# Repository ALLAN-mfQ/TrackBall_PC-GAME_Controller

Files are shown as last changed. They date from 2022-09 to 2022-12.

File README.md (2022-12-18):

## update

2022/12/18  
ジャイロセンサーを追加しました。  

メインボードを新しくしてMPU6050を搭載しました。  
新しい基板はボタンを2つ追加できるようにしてあります。　必要に応じて改造可能です。  
[+GYRO](https://github.com/ALLAN-mfQ/TrackBall_PC-GAME_Controller/tree/main/%2BGYRO)にデータを公開しています。

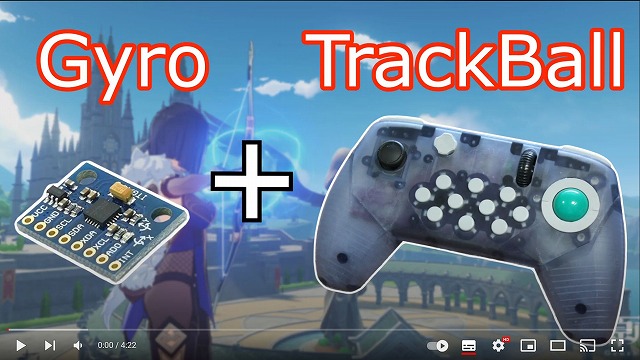
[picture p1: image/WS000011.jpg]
VIDEO (https://www.youtube.com/watch?v=FIJmmkFcd74&t)
   
・メインボードのシルクが一部間違っていたので修正しました。　×　BS.L　→　〇 RB.R  
・KiCadのプロジェクトファイルを公開しました。  

# TrackBall PC GAME Controller

キーボードとマウスとして認識します。  
3Dデータは6.08インチの光造形3Dプリンターで印刷可能です。  
  
This is recognized as a keyboard and mouse when viewed from a PC.  
3D data can be printed with a 6.08" resin 3D printer.  
  
## YouTube
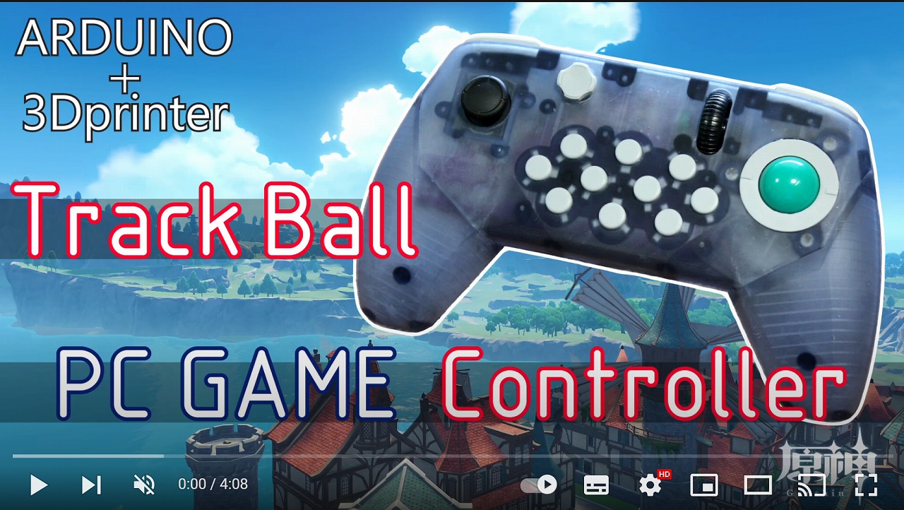
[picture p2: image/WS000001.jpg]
VIDEO (https://www.youtube.com/watch?v=2RWrr7OUH1g&t)
   

# Add library to Arduino IDE.  
  
- https://github.com/zapmaker/OptiMouse  
OptiMouse replaces ADNS2083.cpp and ADNS2083.h with ["OptiMouse_MX8650_fix setting"](https://github.com/ALLAN-mfQ/TrackBall_PC-GAME_Controller/tree/main/Source%20code/OptiMouse_MX8650_fix%20setting).  
  
- https://github.com/nickgammon/Keypad_Matrix  

- https://github.com/PaulStoffregen/Encoder  

--------------------------------------------
#### Placement of programmed switches
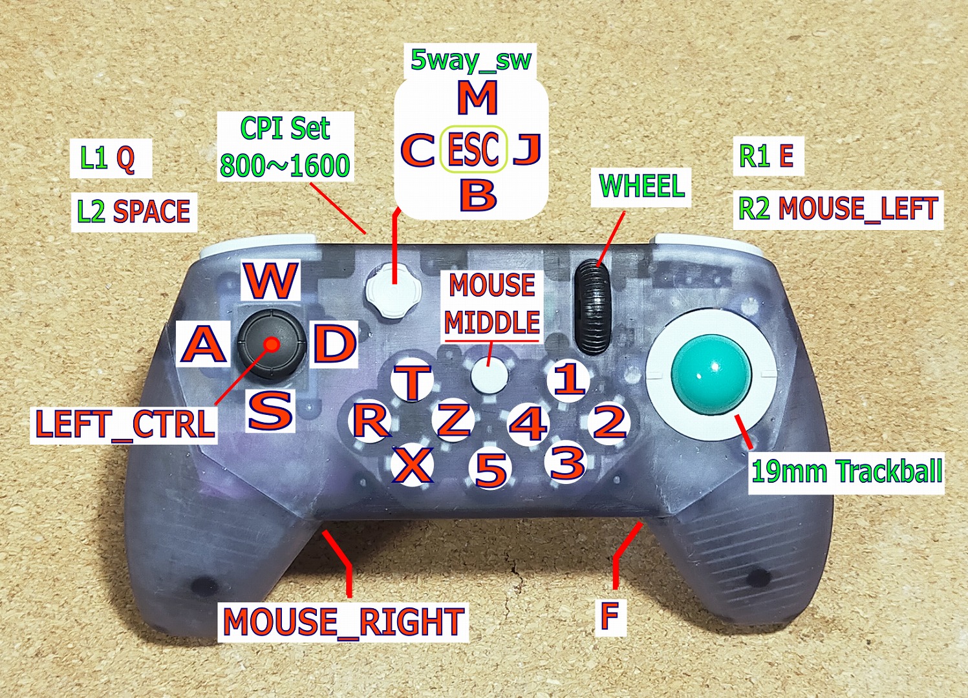
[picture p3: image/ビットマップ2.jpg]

  
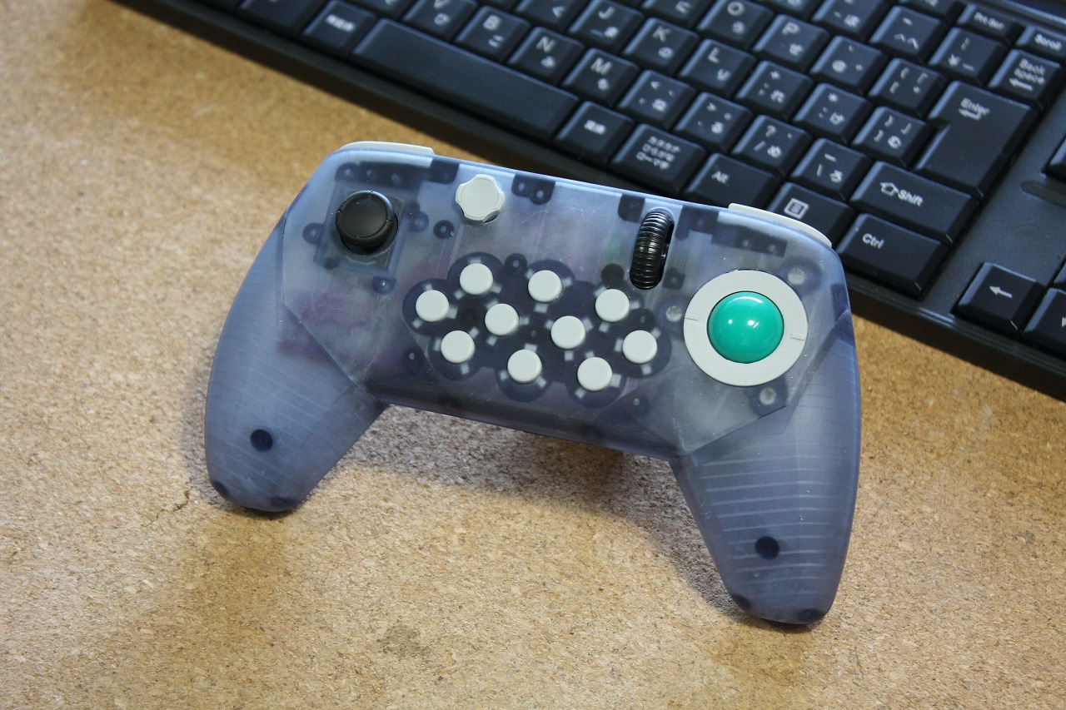
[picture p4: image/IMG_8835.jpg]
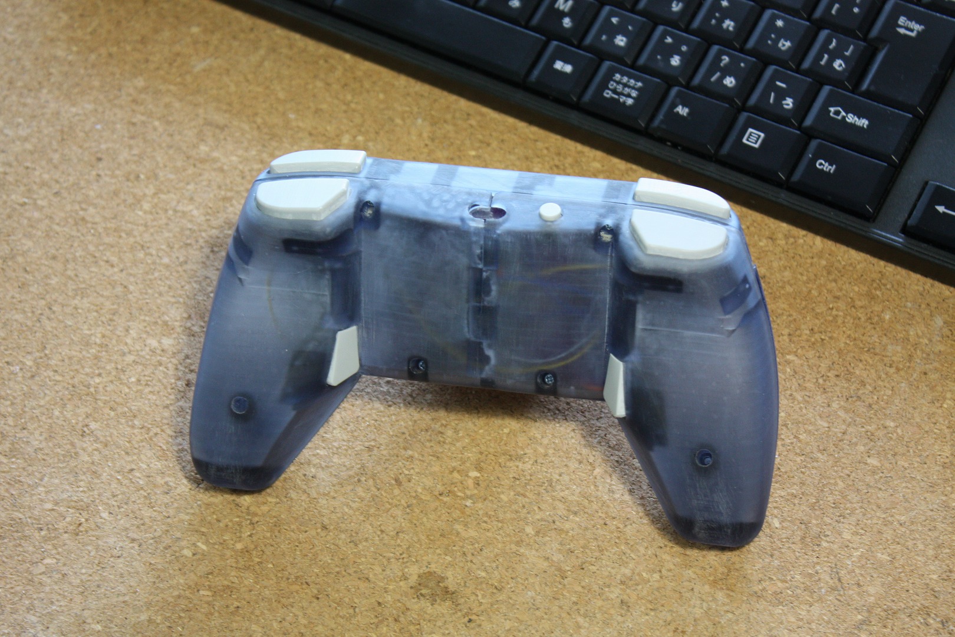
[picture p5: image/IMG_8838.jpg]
   
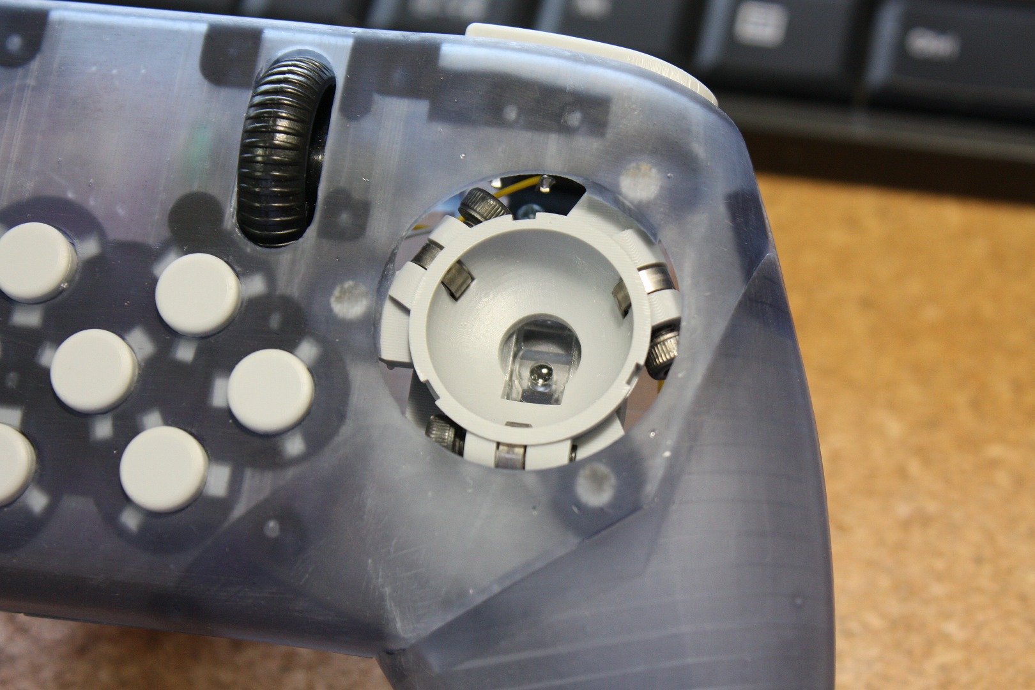
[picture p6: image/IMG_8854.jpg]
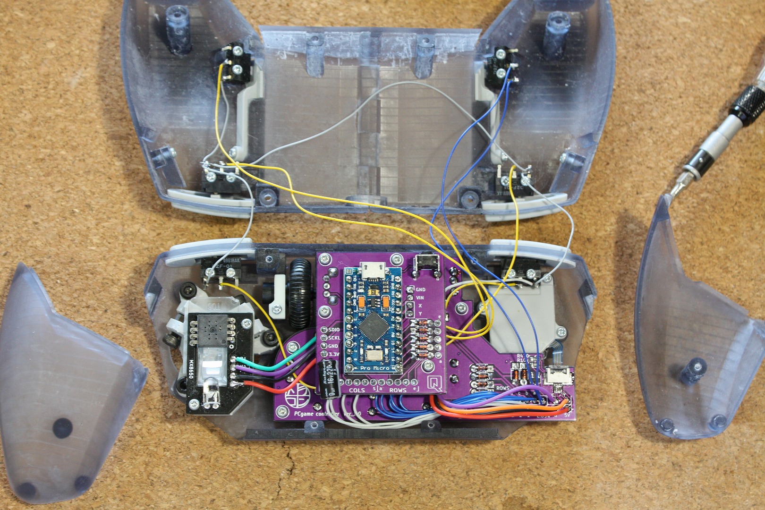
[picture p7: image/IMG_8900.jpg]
   
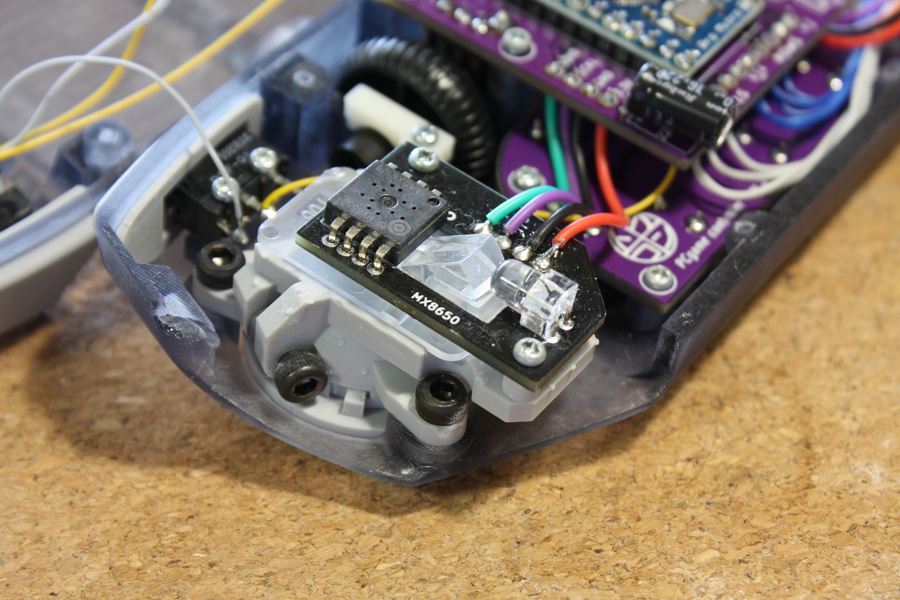
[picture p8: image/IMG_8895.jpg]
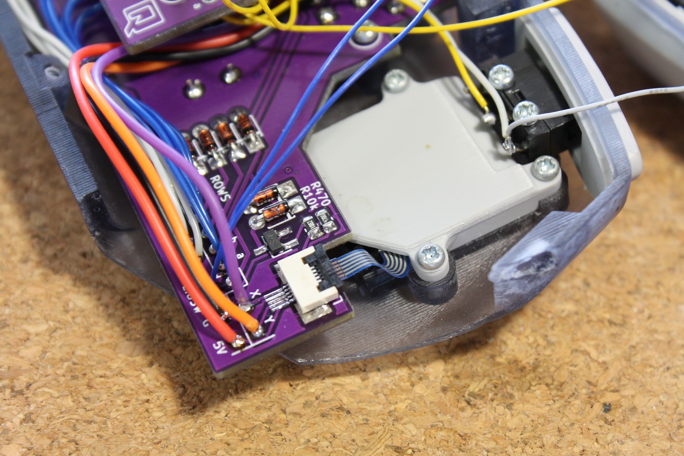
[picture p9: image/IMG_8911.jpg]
   

-------------------------  
# Fusion360 Viewer
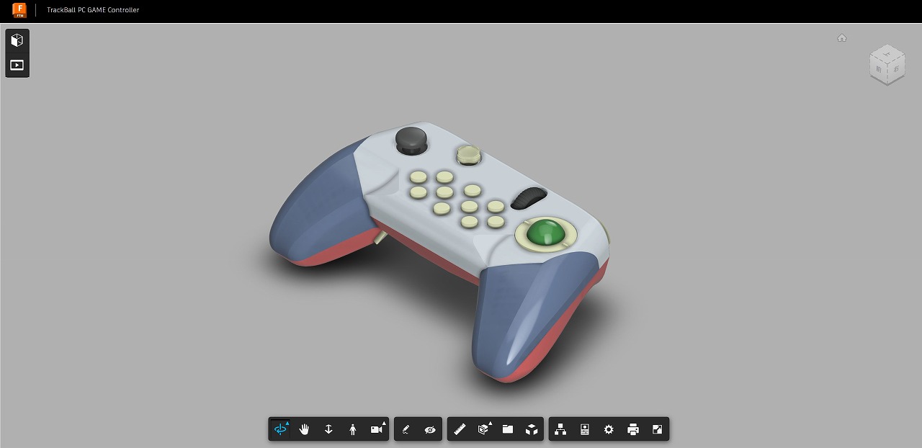
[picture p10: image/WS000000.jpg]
[](https://a360.co/3Qy293e)  

- ## [CAD DATA](https://github.com/ALLAN-mfQ/TrackBall_PC-GAME_Controller/releases/tag/f3z)  
  
-------------------------  
# Social
- [YouTube](https://www.youtube.com/channel/UCiIz3zCHwNroYE9h4h5BDew)  
- [blog](http://ftukurou.blog41.fc2.com/)  
- [Twitter](https://twitter.com/Qdegozaimasu)  
------------------------  
# License
<br />この 作品 は <a rel="license" href="http://creativecommons.org/licenses/by-nc-sa/4.0/">クリエイティブ・コモンズ 表示 - 非営利 - 継承 4.0 国際 ライセンス</a>の下に提供されています。  
  
You are free to:  
- Share — copy and redistribute the material in any medium or format  
- Adapt — remix, transform, and build upon the material  
The licensor cannot revoke these freedoms as long as you follow the license terms.  
  
Under the following terms:  
- Attribution — You must give appropriate credit, provide a link to the license, and indicate if changes were made. You may do so in any reasonable manner, but not in any way that suggests the licensor endorses you or your use.  
  
- NonCommercial — You may not use the material for commercial purposes.  
  
- ShareAlike — If you remix, transform, or build upon the material, you must distribute your contributions under the same license as the original.  
  
- No additional restrictions — You may not apply legal terms or technological measures that legally restrict others from doing anything the license permits.

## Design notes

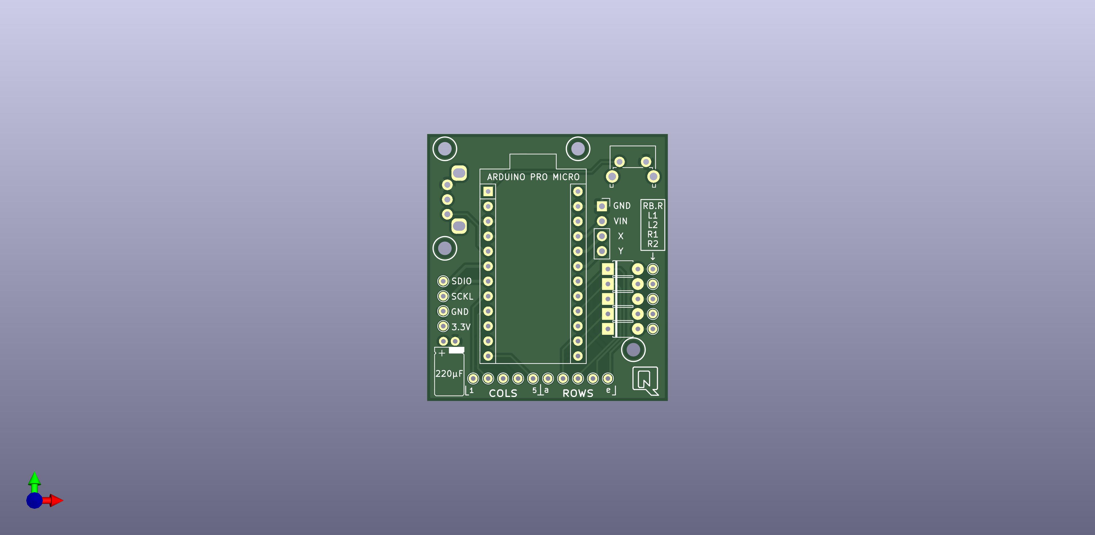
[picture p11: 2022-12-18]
Gerber data/IMG/PCB1-1 (2).jpg

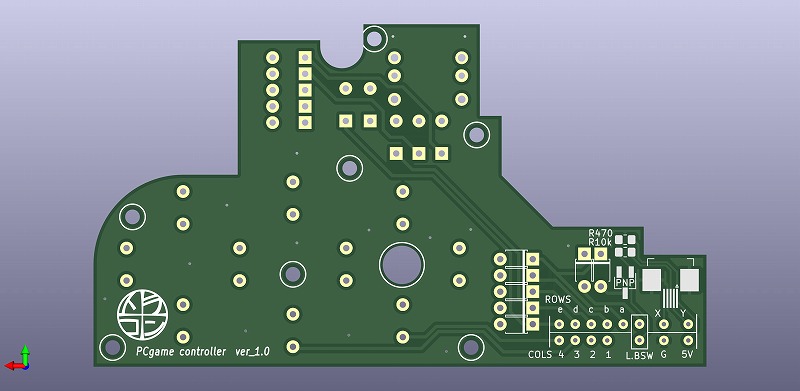
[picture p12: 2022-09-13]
Gerber data/IMG/PCB2-2.jpg

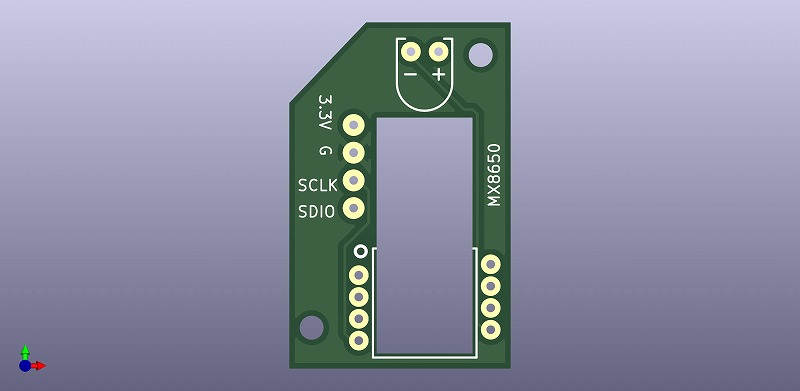
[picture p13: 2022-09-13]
Gerber data/IMG/PCB3-1.jpg

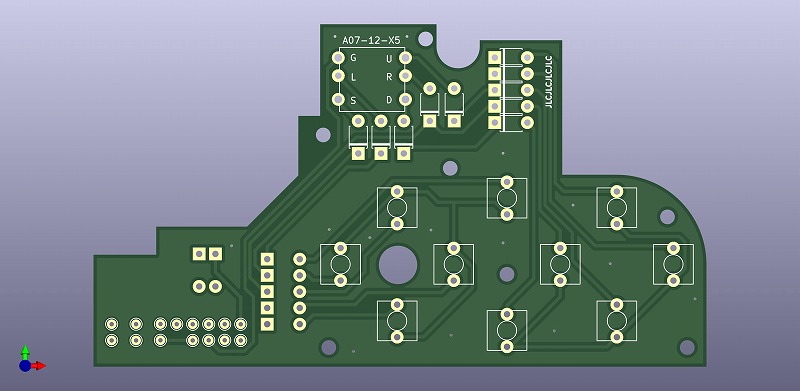
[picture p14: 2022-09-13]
Gerber data/IMG/PCB2-1.jpg

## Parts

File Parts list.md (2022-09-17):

# Parts list  

- 19ｍｍ TrackBall  
[aliexpress](https://www.aliexpress.com/item/1005003039585911.html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,scm-url:1007.40000.303897.0,pvid:a731370d-d380-491d-bfb3-71b697046ee4,tpp_buckets:668%232846%238109%23298&pdp_ext_f=%7B%22sku_id%22%3A%2212000023390290670%22%2C%22sceneId%22%3A%2230050%22%7D&pdp_npi=2%40dis%21JPY%212328.0%211793.0%21%21%21%21%21%40210312f816631597750385142e5643%2112000023390290670%21rec)  

-------------------------------------
(DAISO 300円ワイヤレスマウスから取る)
- Optical Mouse Sensor　MX8650  
- Lens  
- LED  
- Mouse Encoder 9mm  

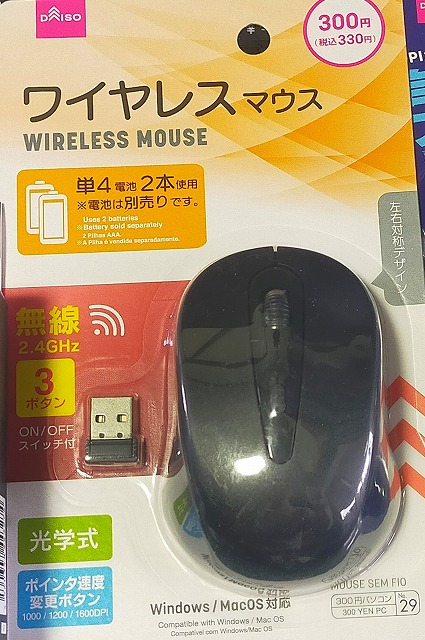
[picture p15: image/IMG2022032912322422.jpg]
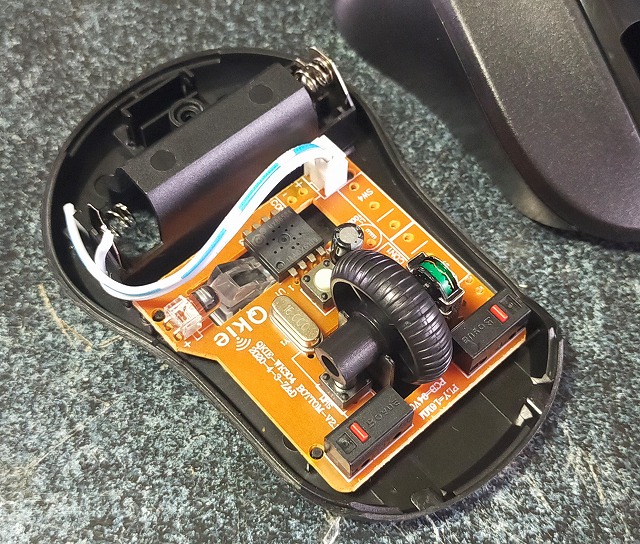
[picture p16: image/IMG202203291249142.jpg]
   

-----------------------------------

- Micro Switch (OMRON D2F-01) /6 piece  

- Tactile Switch 6×6×4.3mm　/ 10 piece  
[aliexpress](https://www.aliexpress.com/item/1005001921970223.html?spm=a2g0o.order_list.0.0.23cc1802IYOi4a)  

- Tactile Switch Right Angle With stent _ 5H  
[aliexpress](https://www.aliexpress.com/item/32906656862.html?spm=a2g0o.order_list.0.0.21ef1802fu9zWF)  

- FPC Connector 0.5mm_5P  
[aliexpress](https://www.aliexpress.com/item/10000000478377.html?spm=a2g0o.order_list.0.0.4ffd1802y0xLD5)  

- DIP 5way Switch(A07-12-X5)  
[aliexpress](https://www.aliexpress.com/item/4000590085207.html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,scm-url:1007.13339.300834.0,pvid:169c9d8b-418e-4232-992f-b9812b1cd60d,tpp_buckets:668%232846%238109%231935&pdp_ext_f=%7B%22sku_id%22%3A%2210000003460325014%22%2C%22sceneId%22%3A%223339%22%7D&pdp_npi=2%40dis%21JPY%21399.0%21399.0%21%21%21%21%21%402101d1bb16631616751134827ece49%2110000003460325014%21rec)  

- Nintend Switch Joystick  
[aliexpress](https://www.aliexpress.com/item/1005002623083913.html?spm=a2g0o.order_list.0.0.4ffd1802y0xLD5)  

- Arduino Pro Micro  
[aliexpress](https://www.aliexpress.com/item/32768308647.html?spm=a2g0o.order_list.0.0.4ffd1802y0xLD5)  

### 0805 Resistor  
- 100R  
- 470R  
- 10K  

### 0805 Capacitor  
- 0.1μF　/ 2 piece  
- 10μF　/ 2 piece   
  　
- PNP Transistor 2SA1162  
- 3 3v Regulator　SOT-89  NJM78L33  
- Diode  1N4148  / 22 piece  
- Electrolytic Capacitor 220μF  
　
- Bearing MR63ZZ (6mm×3mm×2.5mm) / 3 piece  

### Tapping Screw  
- M2×6 /23 piece  
- M2×10 /18 piece  

### allen socket head screw  
- M3×6 /3 piece  
- M3×10 /3 piece  

### Insert nut  
- M3×OD4.2×Lengrh3  / 3 piece

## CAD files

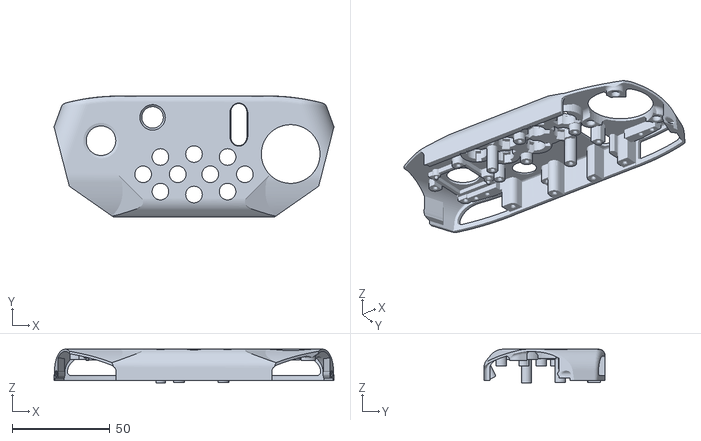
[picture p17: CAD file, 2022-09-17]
STL/top shell_main.stl
143.1 x 61.9 x 17.2

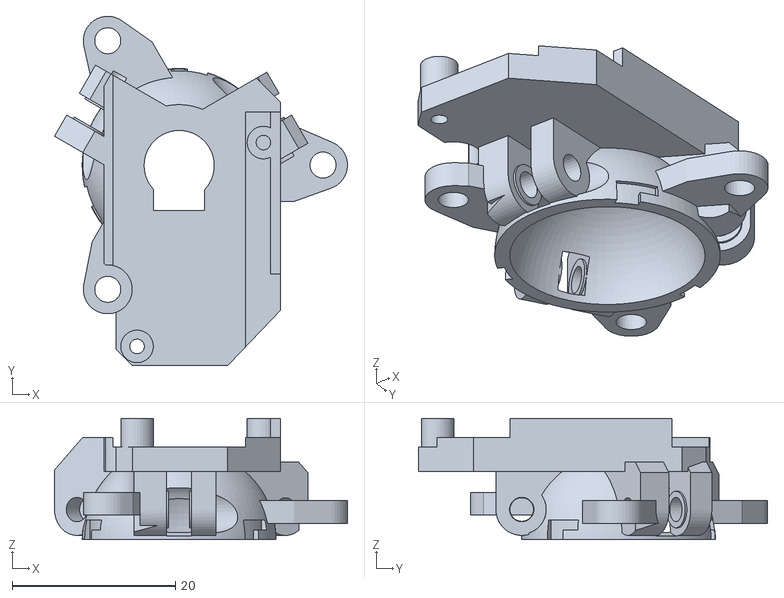
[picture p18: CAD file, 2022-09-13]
STL/TB19mm mount.stl
35.9 x 42.8 x 14.9

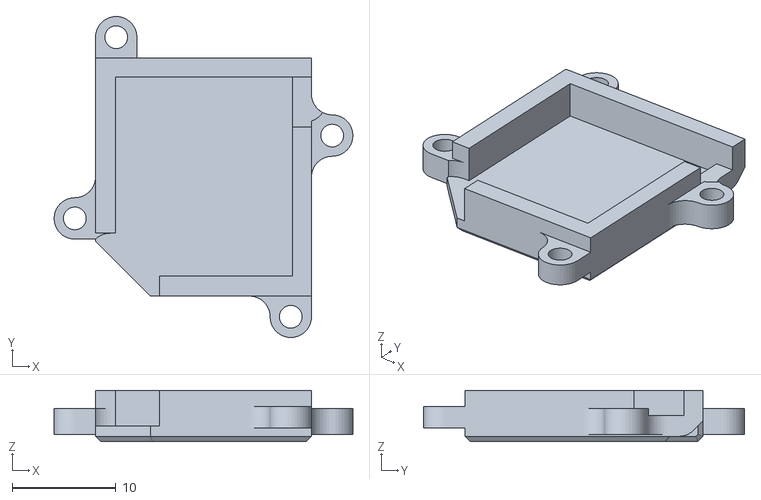
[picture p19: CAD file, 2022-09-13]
STL/joystick_mount.stl
28.9 x 31.0 x 4.93

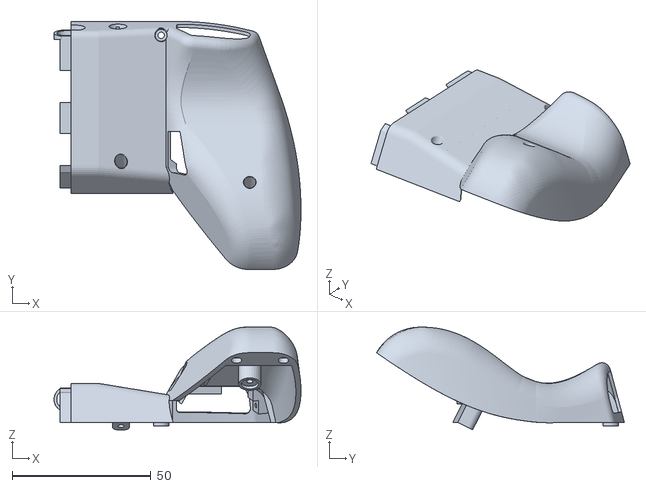
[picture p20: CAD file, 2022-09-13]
STL/Back shell_L.stl
88.9 x 89.2 x 37.0

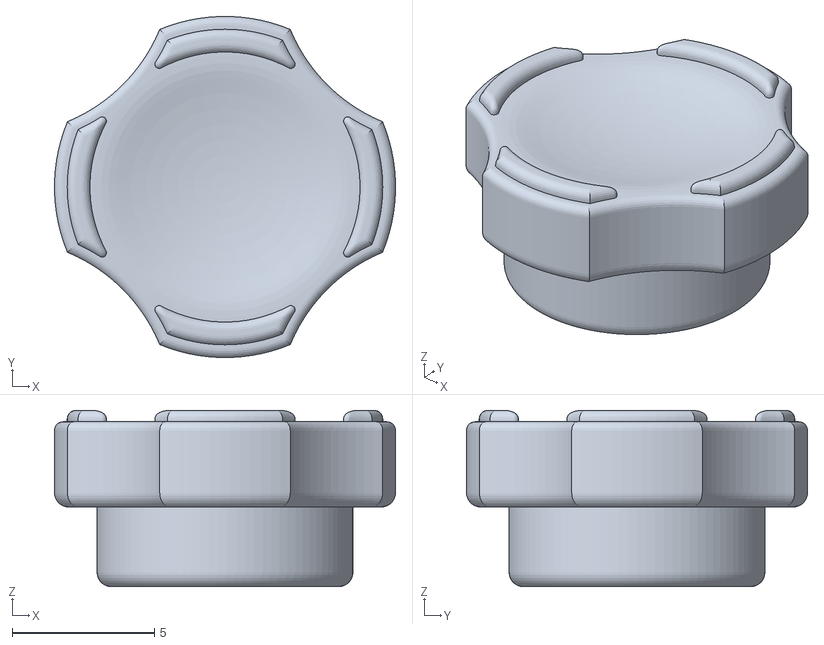
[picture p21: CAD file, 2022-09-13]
STL/5way_SW knob.stl
12.0 x 12.0 x 6.20

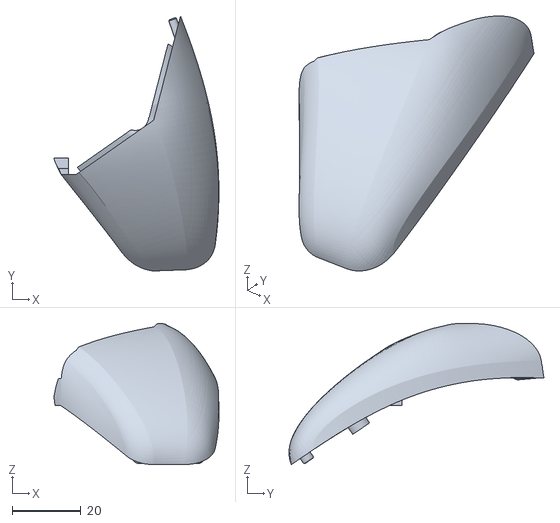
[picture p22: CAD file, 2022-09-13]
STL/top shell_R.stl
48.0 x 74.2 x 41.1

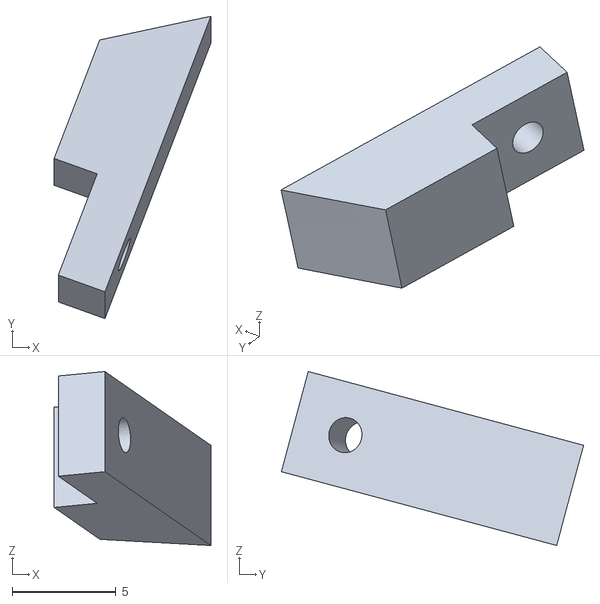
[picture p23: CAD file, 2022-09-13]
STL/LR2 Stopper (2 pieces).stl
7.55 x 14.6 x 8.39

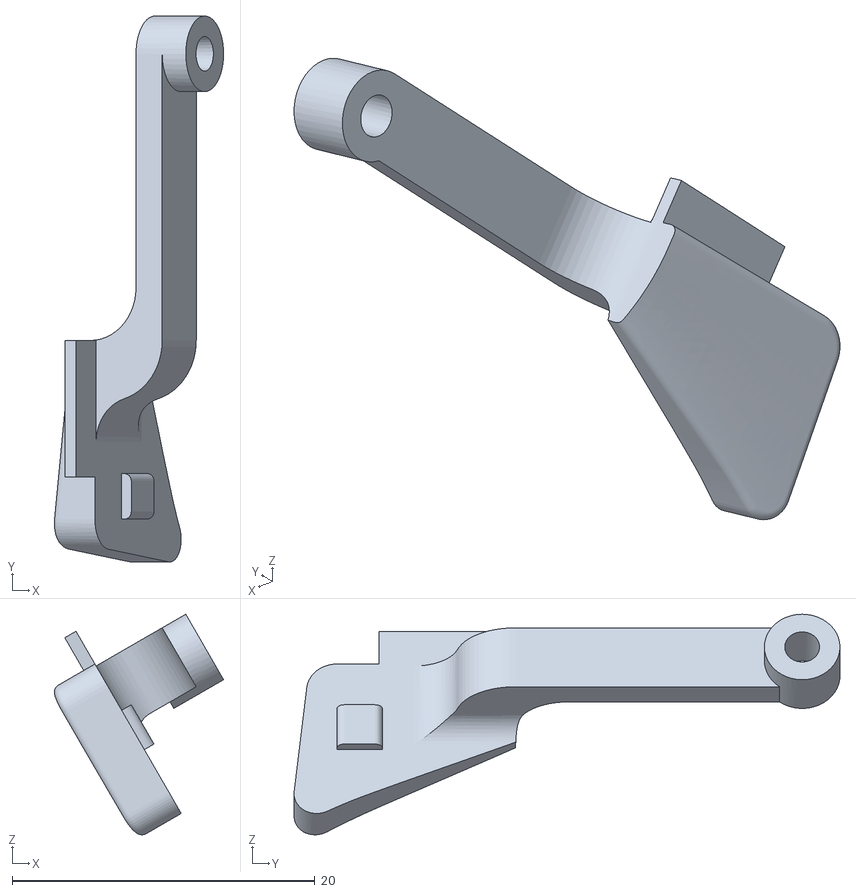
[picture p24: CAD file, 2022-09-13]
STL/back buttonR.stl
11.2 x 36.1 x 14.6

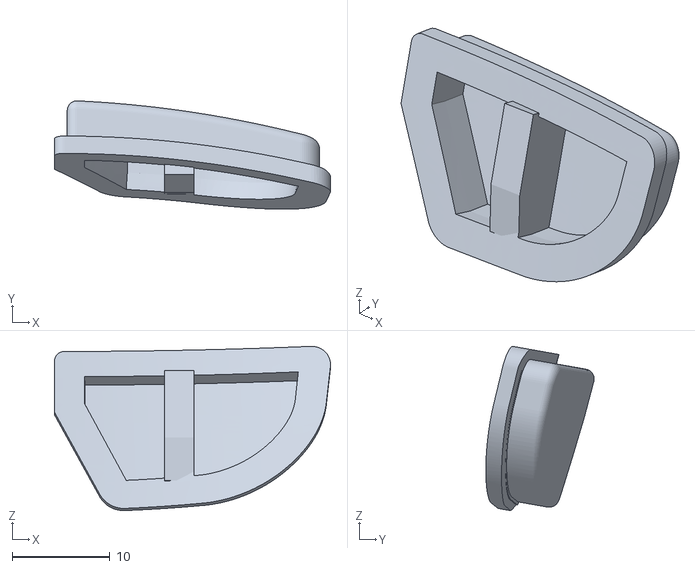
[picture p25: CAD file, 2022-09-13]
STL/R2.stl
28.2 x 11.1 x 16.8

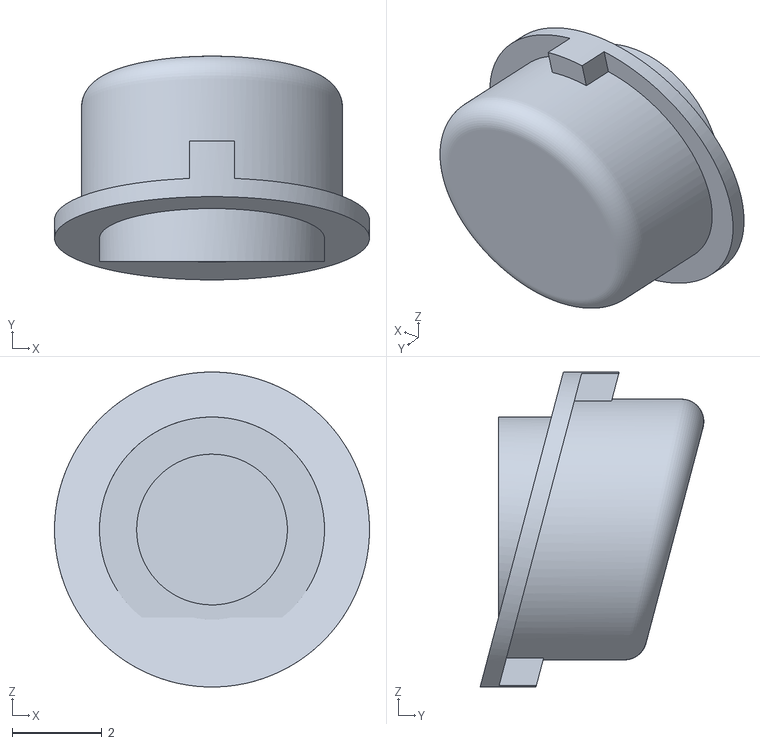
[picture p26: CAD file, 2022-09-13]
STL/set button.stl
7.00 x 4.97 x 7.00

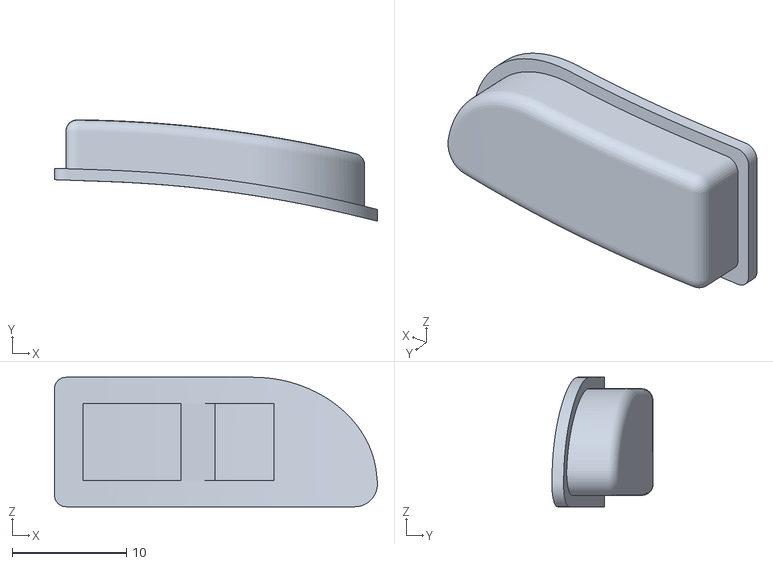
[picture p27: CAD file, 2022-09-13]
STL/R1.stl
28.3 x 8.89 x 11.4

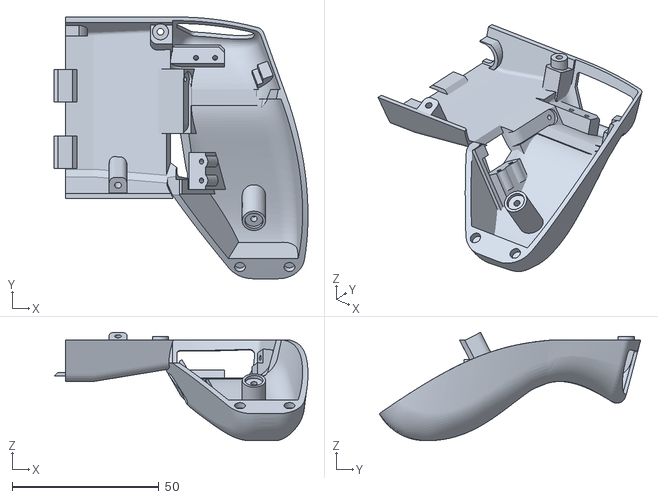
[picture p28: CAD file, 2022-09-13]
STL/Back shell_R.stl
86.7 x 89.2 x 37.0

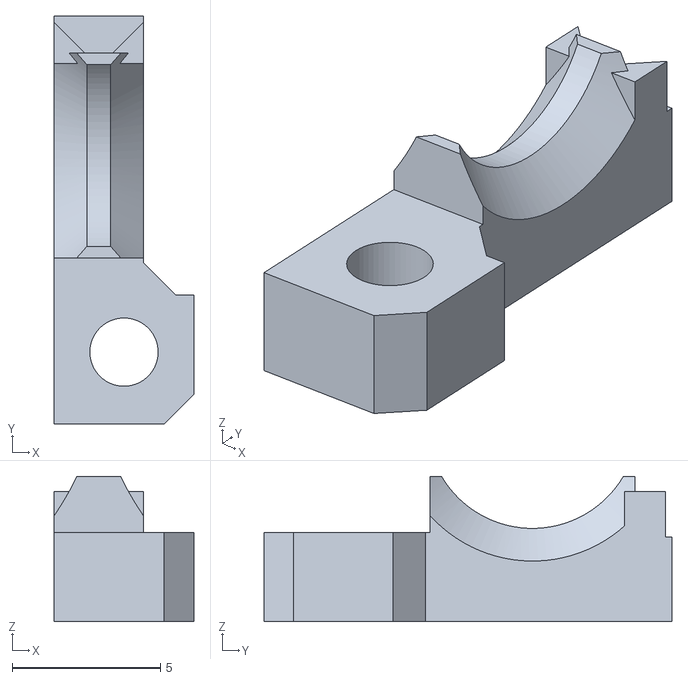
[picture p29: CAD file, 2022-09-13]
STL/Wheel lock.stl
4.70 x 13.7 x 4.89

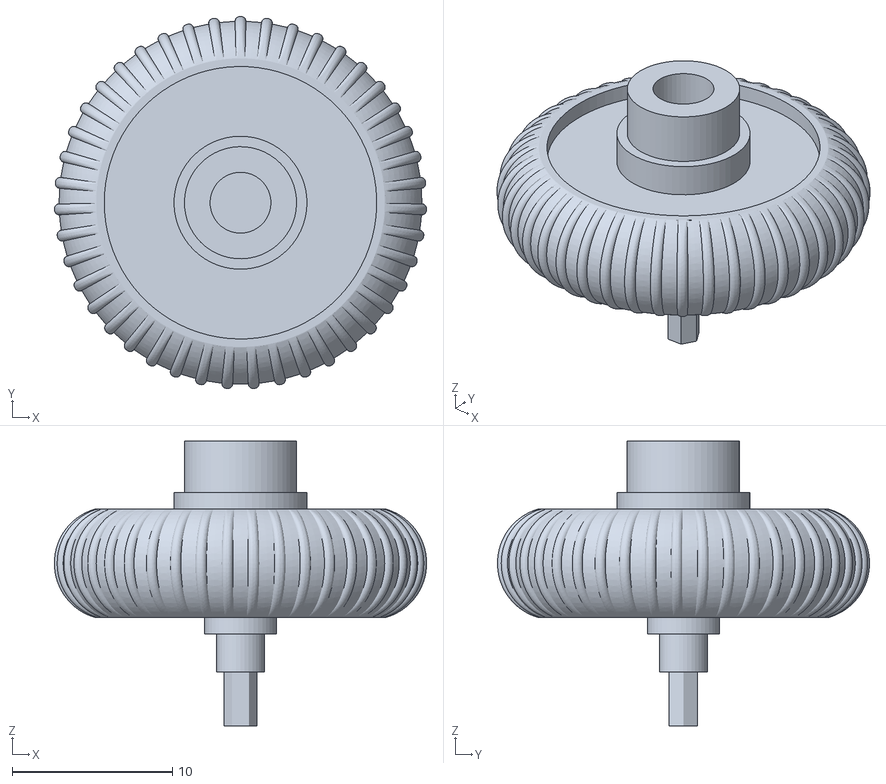
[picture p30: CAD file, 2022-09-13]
STL/wheel.stl
23.2 x 23.2 x 17.8

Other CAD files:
STL/top shell_L.stl
STL/L2.stl
STL/back buttonL.stl
STL/button (10 pieces).stl
STL/L1.stl
STL/TB19mm mount Ring.stl

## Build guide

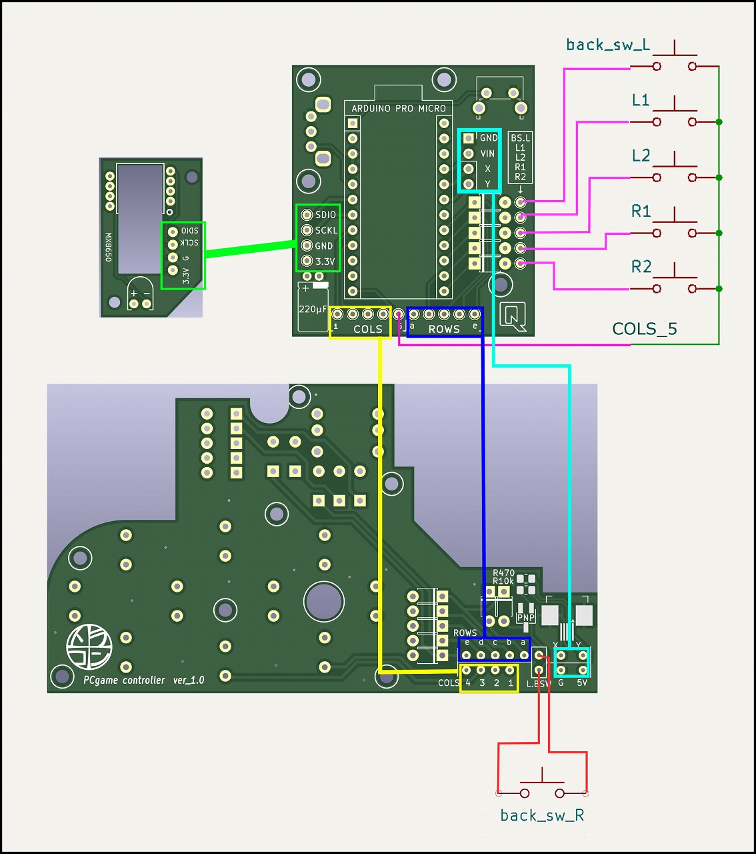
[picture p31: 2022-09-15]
Wiring diagram.jpg

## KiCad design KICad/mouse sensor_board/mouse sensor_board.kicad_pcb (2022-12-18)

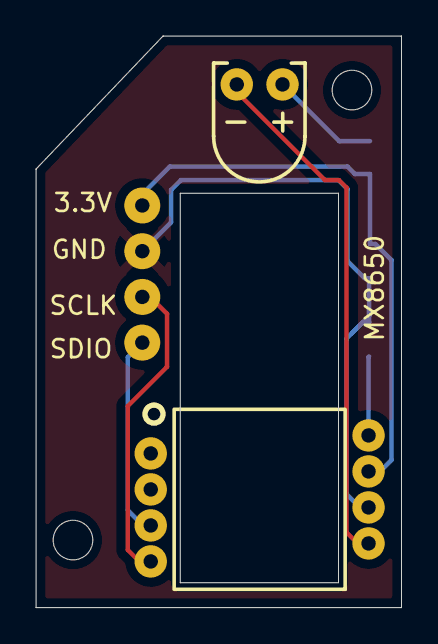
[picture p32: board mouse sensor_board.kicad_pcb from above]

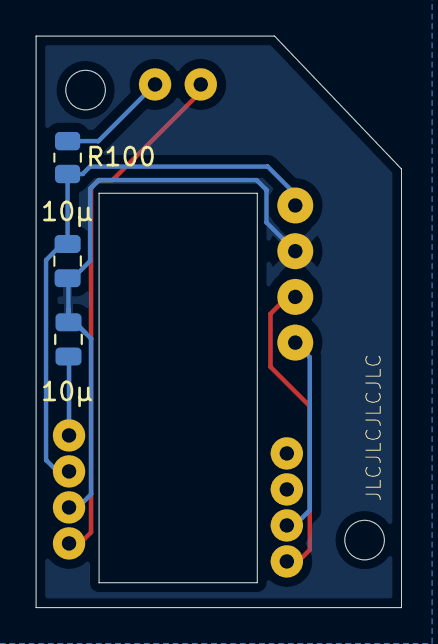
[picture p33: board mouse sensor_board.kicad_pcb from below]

Board: 2 copper layers, 20.3 x 31.8 mm, 6 parts (3 on the bottom side), 3 nets.

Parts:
3.3V: pad_1p
10μ: C10μ; C_0805_2012Metric
10μ#2: C; C_0805_2012Metric
GND: pad_1p
R100: R; R_0805_2012Metric
U1: MX8650; MX89650

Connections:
+3V3: 3.3V.1, 10μ.1, R100.2, U1.7 (VDD)
GND: 10μ.2, 10μ#2.2, GND.1, U1.6 (GND)
unnamed: 10μ#2.1, U1.8 (VDDA)

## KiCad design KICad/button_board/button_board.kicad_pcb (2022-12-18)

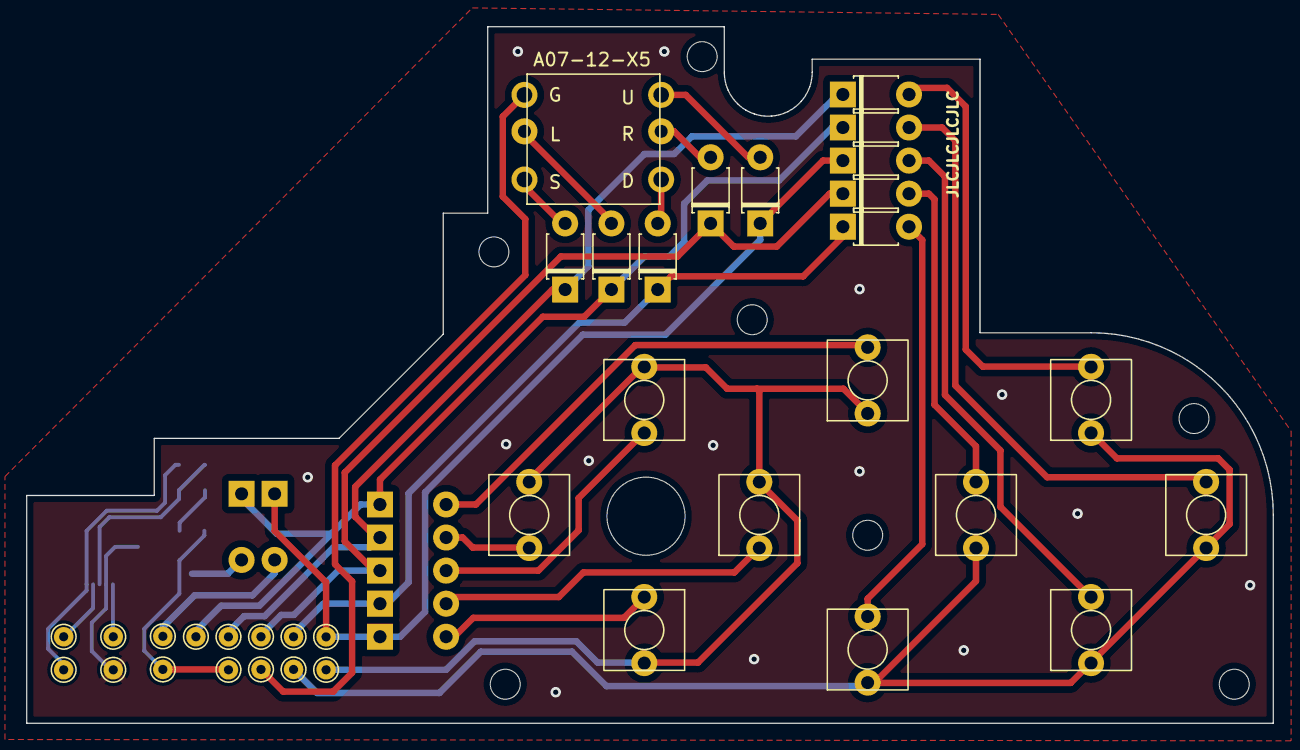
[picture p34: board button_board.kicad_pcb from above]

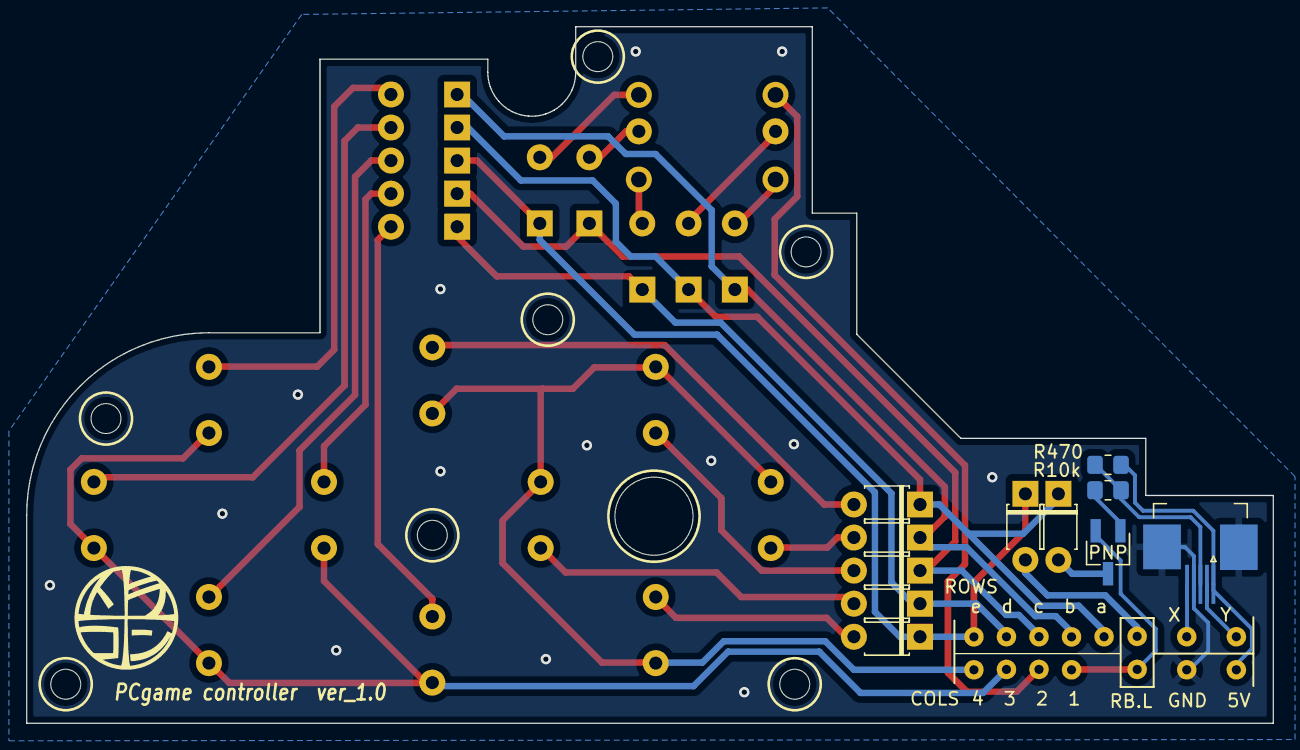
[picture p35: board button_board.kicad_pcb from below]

Board: 2 copper layers, 95.8 x 53.5 mm, 4 parts (3 on the bottom side), 2 nets.

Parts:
A07-12-X5: A07-12-X5
PNP: SC-59_Handsoldering
R10k, R470: R_0805_2012Metric_Pad1.20x1.40mm_HandSolder

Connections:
jsw: R10k.2, R470.1
jsw2: PNP.1, R10k.1

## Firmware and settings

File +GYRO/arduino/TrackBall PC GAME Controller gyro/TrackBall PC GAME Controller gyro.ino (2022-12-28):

#include "Keypad_Matrix.h"
#include "Keyboard.h"
#include "Mouse.h"
#include "ADNS2083.h"
#include "Encoder.h"
#include <Wire.h>

#include <Kalman.h> 
#define RESTRICT_PITCH // Comment out to restrict roll to ±90deg instead - please read: http://www.freescale.com/files/sensors/doc/app_note/AN3461.pdf

#define ENCODER_DO_NOT_USE_INTERRUPTS
#define KEY_SPACE 0x20
#define SCLK 5                            //マウスセンサーピン
#define SDIO 4                            //
#define _Config 0x06

#define SENS_Y 0.5 //ジャイロ縦軸感度
#define DRIFT_X -1.5 //ドリフト補正
#define DRIFT_Y -3

Kalman kalmanX; // Create the Kalman instances
Kalman kalmanY;

/* IMU Data */
double accX, accY, accZ;
double gyroX, gyroY, gyroZ;
int16_t tempRaw;

double gyroXangle, gyroYangle; // Angle calculate using the gyro only
double compAngleX, compAngleY; // Calculated angle using a complementary filter
double kalAngleX, kalAngleY; // Calculated angle using a Kalman filter

uint32_t timer;
uint8_t i2cData[14]; // Buffer for I2C data

static char on_gyro =0;
static char on_gyro2 =0;
ADNS2083 Optical1 = ADNS2083(SCLK, SDIO);

const int xAxis = A3;         // joystick X axis
const int yAxis = A2;         // joystick Y axis

// parameters for reading the joystick:
int range = 50;               // output range of X or Y movement
int threshold = range / 10;    // resting threshold
int center = range / 2;       // resting position value
static char jbf =0;

volatile static char cpi=2;
volatile static char cpi_set=0;
signed char x = 0;                        
signed char y = 0;                        
static signed char r = 0;
Encoder myEnc(1,0);    //ロータリーエンコーダーに使う端子。

const byte ROWS = 5;    //キーマトリクスの端子数
const byte COLS = 5;

//ボタン設定
/*******************************************************
                                5way_sw
                  w               6           L1            R1                      
                  ↑               ↑          [24]          [22]                           
               a← ● →d        9← (10) →7      L2            R2                                
joystick_button _/↓               ↓          [23]          [21]                           
                  s               8                                                                  
                          
              [11]        [15]         [16]         back_L    back_R                                            
         [14]      [12]          [19]       [17]      [5]      [25]                                             
              [13]        [20]         [18]                                                                     
                                                                                                           
                    
    {joystick_button  ,9   ,17  ,15  ,21}
    {sw3(option) ,10  ,16  ,14  ,22}
    {sw2(option) ,7    ,19  ,11  ,23}
    {sw1(PCIset) ,8    ,20  ,12  ,24}
    {5  ,6   ,18  ,13  ,25}
*********************************************************/
#define _gyro '8' //gyro on/off
#define _CPI '9'  //CPI set
#define _SW3 '6'  //option button sw3
#define _SW2 '7'  //option button sw2

const char keys[ROWS][COLS] = {
 
  {_gyro,'c','2',MOUSE_MIDDLE,MOUSE_LEFT},
  {_SW3,KEY_ESC,'1','r','e'},
  {_SW2, 'j','4','t',KEY_SPACE},
  {_CPI, 'b','5','z','q'},
  {MOUSE_RIGHT, 'm', '3','x','f'},

};

const byte rowPins[ROWS] = {10, 16, 14,15,18}; //ダイオード側connect to the row pinouts of the keypad
const byte colPins[COLS] = {6, 7, 8,9,19}; //connect to the column pinouts of the keypad

  // Create the Keypad
Keypad_Matrix kpd = Keypad_Matrix( makeKeymap (keys), rowPins, colPins, ROWS, COLS );




void setup() 
{ 
  Serial.begin (115200);
  Wire.begin();

 #if ARDUINO >= 157
  Wire.setClock(400000UL); // Set I2C frequency to 400kHz
#else
  TWBR = ((F_CPU / 400000UL) - 16) / 2; // Set I2C frequency to 400kHz
#endif

  i2cData[0] = 7; // Set the sample rate to 1000Hz - 8kHz/(7+1) = 1000Hz
  i2cData[1] = 0x00; // Disable FSYNC and set 260 Hz Acc filtering, 256 Hz Gyro filtering, 8 KHz sampling
  i2cData[2] = 0x00; // Set Gyro Full Scale Range to ±250deg/s
  i2cData[3] = 0x00; // Set Accelerometer Full Scale Range to ±2g
  while (i2cWrite(0x19, i2cData, 4, false)); // Write to all four registers at once
  while (i2cWrite(0x6B, 0x01, true)); // PLL with X axis gyroscope reference and disable sleep mode

  while (i2cRead(0x75, i2cData, 1));
  if (i2cData[0] != 0x68) { // Read "WHO_AM_I" register
    Serial.print(F("Error reading sensor"));
    while (1);
  }
 delay(100);
  /* Set kalman and gyro starting angle */
  while (i2cRead(0x3B, i2cData, 6));
  accX = (int16_t)((i2cData[0] << 8) | i2cData[1]);
  accY = (int16_t)((i2cData[2] << 8) | i2cData[3]);
  accZ = (int16_t)((i2cData[4] << 8) | i2cData[5]);

  // Source: http://www.freescale.com/files/sensors/doc/app_note/AN3461.pdf eq. 25 and eq. 26
  // atan2 outputs the value of -π to π (radians) - see http://en.wikipedia.org/wiki/Atan2
  // It is then converted from radians to degrees
#ifdef RESTRICT_PITCH // Eq. 25 and 26
  double roll  = atan2(accY, accZ) * RAD_TO_DEG;
  double pitch = atan(-accX / sqrt(accY * accY + accZ * accZ)) * RAD_TO_DEG;
#else // Eq. 28 and 29
  double roll  = atan(accY / sqrt(accX * accX + accZ * accZ)) * RAD_TO_DEG;
  double pitch = atan2(-accX, accZ) * RAD_TO_DEG;
#endif

  kalmanX.setAngle(roll); // Set starting angle
  kalmanY.setAngle(pitch);
  gyroXangle = roll;
  gyroYangle = pitch;
  compAngleX = roll;
  compAngleY = pitch;

  timer = micros();


  Optical1.begin();                       // Resync (not really necessary?)
  writeRegister(_Config,0x02);     //CPI設定  800 0 / 1000 0x01 / 1200 0x02 /1600 0x03
  Keyboard.begin();


  kpd.begin ();
  kpd.setKeyDownHandler (keyDown);
  kpd.setKeyUpHandler   (keyUp);
  

  Mouse.begin();
  
 delay(100);
}


void loop()
{

/* Update all the values */
  while (i2cRead(0x3B, i2cData, 14));
  accX = (int16_t)((i2cData[0] << 8) | i2cData[1]);
  accY = (int16_t)((i2cData[2] << 8) | i2cData[3]);
  accZ = (int16_t)((i2cData[4] << 8) | i2cData[5]);
  tempRaw = (int16_t)((i2cData[6] << 8) | i2cData[7]);
  gyroX = (int16_t)((i2cData[8] << 8) | i2cData[9]);
  gyroY = (int16_t)((i2cData[10] << 8) | i2cData[11]);
  gyroZ = (int16_t)((i2cData[12] << 8) | i2cData[13]);;

  double dt = (double)(micros() - timer) / 1000000; // Calculate delta time
  timer = micros();
 // Source: http://www.freescale.com/files/sensors/doc/app_note/AN3461.pdf eq. 25 and eq. 26
  // atan2 outputs the value of -π to π (radians) - see http://en.wikipedia.org/wiki/Atan2
  // It is then converted from radians to degrees
#ifdef RESTRICT_PITCH // Eq. 25 and 26
  double roll  = atan2(accY, accZ) * RAD_TO_DEG;
  double pitch = atan(-accX / sqrt(accY * accY + accZ * accZ)) * RAD_TO_DEG;
#else // Eq. 28 and 29
  double roll  = atan(accY / sqrt(accX * accX + accZ * accZ)) * RAD_TO_DEG;
  double pitch = atan2(-accX, accZ) * RAD_TO_DEG;
#endif

  double gyroXrate = gyroX / 131.0; // Convert to deg/s
  double gyroYrate = gyroY / 131.0; // Convert to deg/s

#ifdef RESTRICT_PITCH
  // This fixes the transition problem when the accelerometer angle jumps between -180 and 180 degrees
  if ((roll < -90 && kalAngleX > 90) || (roll > 90 && kalAngleX < -90)) {
    kalmanX.setAngle(roll);
    compAngleX = roll;
    kalAngleX = roll;
    gyroXangle = roll;
  } else
    kalAngleX = kalmanX.getAngle(roll, gyroXrate, dt); // Calculate the angle using a Kalman filter

  if (abs(kalAngleX) > 90)
    gyroYrate = -gyroYrate; // Invert rate, so it fits the restriced accelerometer reading
  kalAngleY = kalmanY.getAngle(pitch, gyroYrate, dt);
#else
  // This fixes the transition problem when the accelerometer angle jumps between -180 and 180 degrees
  if ((pitch < -90 && kalAngleY > 90) || (pitch > 90 && kalAngleY < -90)) {
    kalmanY.setAngle(pitch);
    compAngleY = pitch;
    kalAngleY = pitch;
    gyroYangle = pitch;
  } else
    kalAngleY = kalmanY.getAngle(pitch, gyroYrate, dt); // Calculate the angle using a Kalman filter

  if (abs(kalAngleY) > 90)
    gyroXrate = -gyroXrate; // Invert rate, so it fits the restriced accelerometer reading
  kalAngleX = kalmanX.getAngle(roll, gyroXrate, dt); // Calculate the angle using a Kalman filter
#endif

  gyroXangle += gyroXrate * dt; // Calculate gyro angle without any filter
  gyroYangle += gyroYrate * dt;
  //gyroXangle += kalmanX.getRate() * dt; // Calculate gyro angle using the unbiased rate
  //gyroYangle += kalmanY.getRate() * dt;

  compAngleX = 0.93 * (compAngleX + gyroXrate * dt) + 0.07 * roll; // Calculate the angle using a Complimentary filter
  compAngleY = 0.93 * (compAngleY + gyroYrate * dt) + 0.07 * pitch;

  // Reset the gyro angle when it has drifted too much
  if (gyroXangle < -180 || gyroXangle > 180)
    gyroXangle = kalAngleX;
  if (gyroYangle < -180 || gyroYangle > 180)
    gyroYangle = kalAngleY;

  /* Print Data */
#if 0 // Set to 1 to activate
  Serial.print(accX); Serial.print("\t");
  Serial.print(accY); Serial.print("\t");
  Serial.print(accZ); Serial.print("\t");

  Serial.print(gyroX/131); Serial.print("\t");
  Serial.print(gyroY/131); Serial.print("\t");
  Serial.print(gyroZ/131); Serial.print("\t");

  Serial.print("\t");
#endif

if(on_gyro == 1)
Mouse.move((-((gyroZ+gyroX)/2)/131)DRIFT_X, ((-gyroY/131)DRIFT_Y)*SENS_Y,0);

//ホイール　ロータリーエンコーダー
  r = myEnc.read();
 if(r <= -1)
 r= -1;
 else if(r >= 1)
 r= 1;
 myEnc.write(0);
 //
   
  kpd.scan ();  //キーボード
   
//マウス
    x = Optical1.dx();  
    y = Optical1.dy(); 
  //x =~ (Optical1.dx() - 1);                   // 方向を反転する場合
  //y =~ (Optical1.dy() - 1); 
                     
   Optical1.mo();         //Motion_Status読み取り    
   Mouse.move(x, y, r);  




         //CPI変更SW
          if(cpi_set==1){
            delay(500);
            Serial.print ("_:");
           if(cpi==0){writeRegister(_Config,0x00); Serial.print ("CPI-800");}
           if(cpi==1){writeRegister(_Config,0x01); Serial.print ("CPI-1000");}
           if(cpi==2){writeRegister(_Config,0x02); Serial.print ("CPI-1200");}
           if(cpi==3){writeRegister(_Config,0x03); Serial.print ("CPI-1600");}     
            cpi_set=0;
            cpi ++;
            if(cpi > 3) cpi =0;
         }
         //
         
 // read and scale the two axes:

   int xReading = readAxis(A3);
   int yReading = readAxis(A2);
   
          if(xReading > 8){
      Keyboard.press('d');
         }
      
      else if(xReading < -8){
      Keyboard.press('a');
      }
    
      if(yReading > 8){
      Keyboard.press('s');
         }
      else if(yReading < -8){
      Keyboard.press('w');
      }

if(xReading == 0) {
       Keyboard.release('a');
       Keyboard.release('d');
}

if(yReading == 0) {
       Keyboard.release('w');
       Keyboard.release('s');
}


 
 }//main end


//レジスタ書き込み関数
void writeRegister(uint8_t address, uint8_t data)
{
  int i = 7;
  
  // Set MSB high, to indicate write operation:
  address |= 0x80;
  
  // Write the address:
  pinMode (SDIO, OUTPUT);
  for (; i>=0; i--)
  {
    digitalWrite (SCLK, LOW);
    digitalWrite (SDIO, address & (1 << i));
    digitalWrite (SCLK, HIGH);
  }
  
  // Write the data:
  for (i=7; i>=0; i--)
  {
    digitalWrite (SCLK, LOW);
    digitalWrite (SDIO, data & (1 << i));
    digitalWrite (SCLK, HIGH);
  }
}

///////////////////////////////////////
//キー検出関数
void keyDown (const char which)
  {
     Serial.print (F("Key down: "));
     Serial.println (which);
if(which == _CPI) cpi_set =1;

if(which == _gyro){
  if(on_gyro2 == 0) {on_gyro =1; on_gyro2 =1;}
  else if(on_gyro2 == 1) {on_gyro =0; on_gyro2 =0;}
}

if(which != MOUSE_LEFT && which != MOUSE_RIGHT && which != MOUSE_MIDDLE && which !=_CPI && which != _gyro)
  Keyboard.press(which);


  
    if(which == MOUSE_LEFT)
     if (!Mouse.isPressed(MOUSE_LEFT))
    Mouse.press(MOUSE_LEFT);

    if(which == MOUSE_RIGHT)
     if (!Mouse.isPressed(MOUSE_RIGHT))
    Mouse.press(MOUSE_RIGHT);

    if(which == MOUSE_MIDDLE)
     if (!Mouse.isPressed(MOUSE_MIDDLE))
    Mouse.press(MOUSE_MIDDLE);

  }

void keyUp (const char which)
  {
  Serial.print (F("Key up: "));
  Serial.println (which);

  if(which != MOUSE_LEFT && which != MOUSE_RIGHT && which != MOUSE_MIDDLE && which != _CPI && which != _gyro){
  Keyboard.release(which);
  }
  if(which == MOUSE_LEFT)
    if (Mouse.isPressed(MOUSE_LEFT))
    Mouse.release(MOUSE_LEFT);

    if(which == MOUSE_RIGHT)
    if (Mouse.isPressed(MOUSE_RIGHT))
    Mouse.release(MOUSE_RIGHT);

    if(which == MOUSE_MIDDLE)
    if (Mouse.isPressed(MOUSE_MIDDLE))
    Mouse.release(MOUSE_MIDDLE);
  }
  

int readAxis(int thisAxis) {
  // read the analog input:
  int reading = analogRead(thisAxis);

  // map the reading from the analog input range to the output range:
  reading = map(reading, 0, 1023, 0, range);

  // if the output reading is outside from the rest position threshold, use it:
  int distance = reading - center;

  if (abs(distance) < threshold) {
    distance = 0;
  }

  // return the distance for this axis:
  return distance;
}

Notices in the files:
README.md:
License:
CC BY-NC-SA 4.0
